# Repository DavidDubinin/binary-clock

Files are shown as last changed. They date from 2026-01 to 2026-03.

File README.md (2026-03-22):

# BINARY CLOCK SIGMA EDITION AVR CODE - ATMEGA48

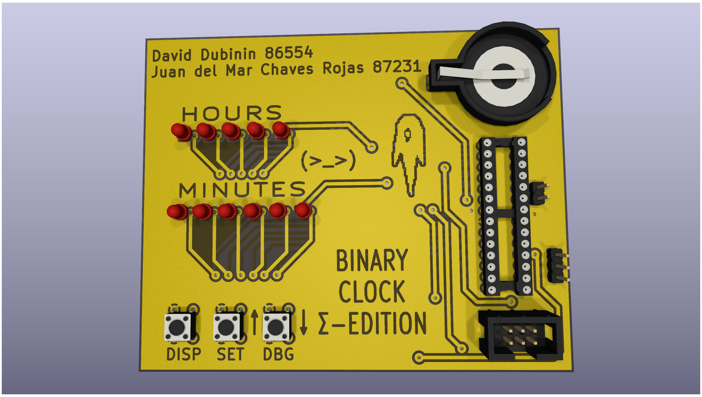
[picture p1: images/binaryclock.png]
pcb_render

schematic
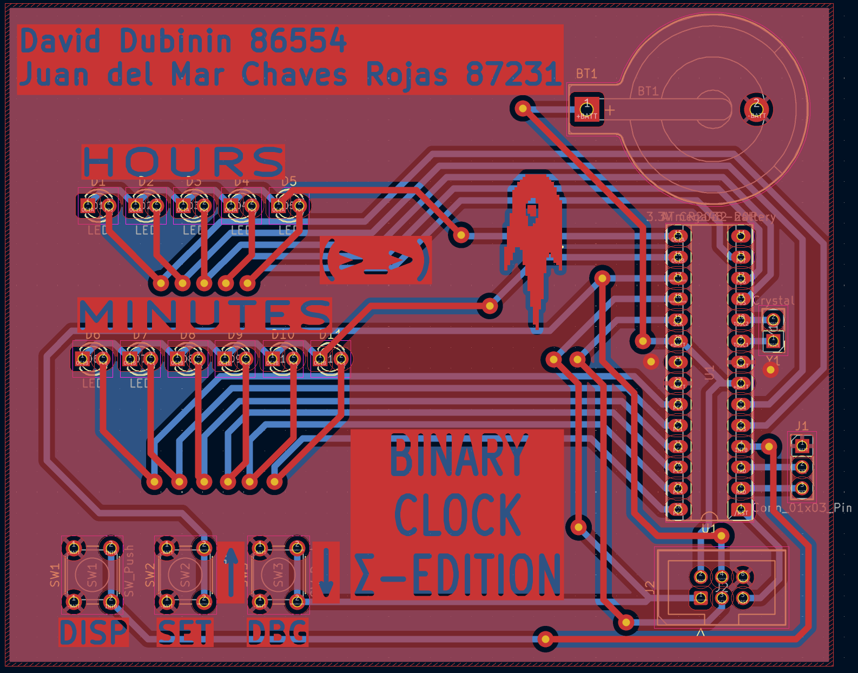
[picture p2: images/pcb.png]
pcb


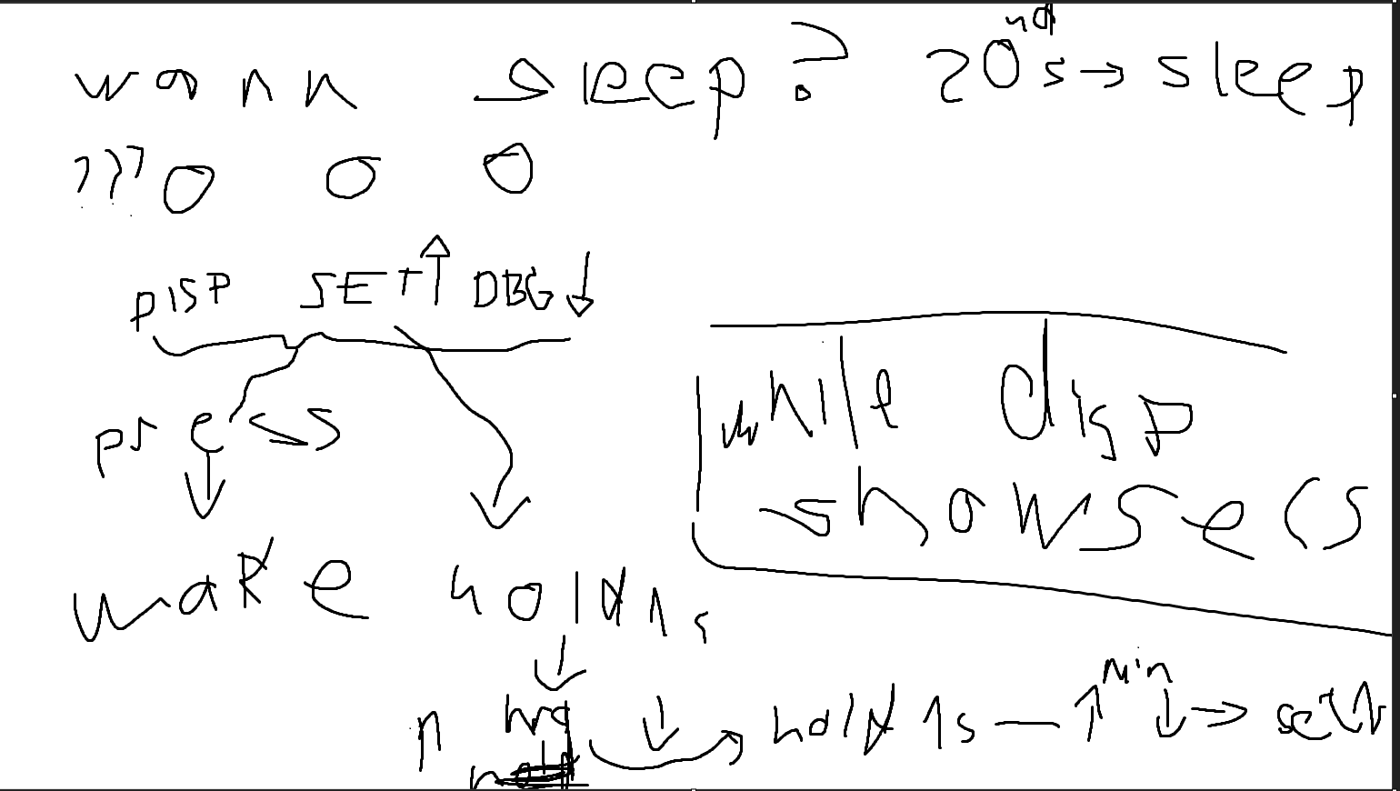
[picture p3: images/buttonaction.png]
buttonaction

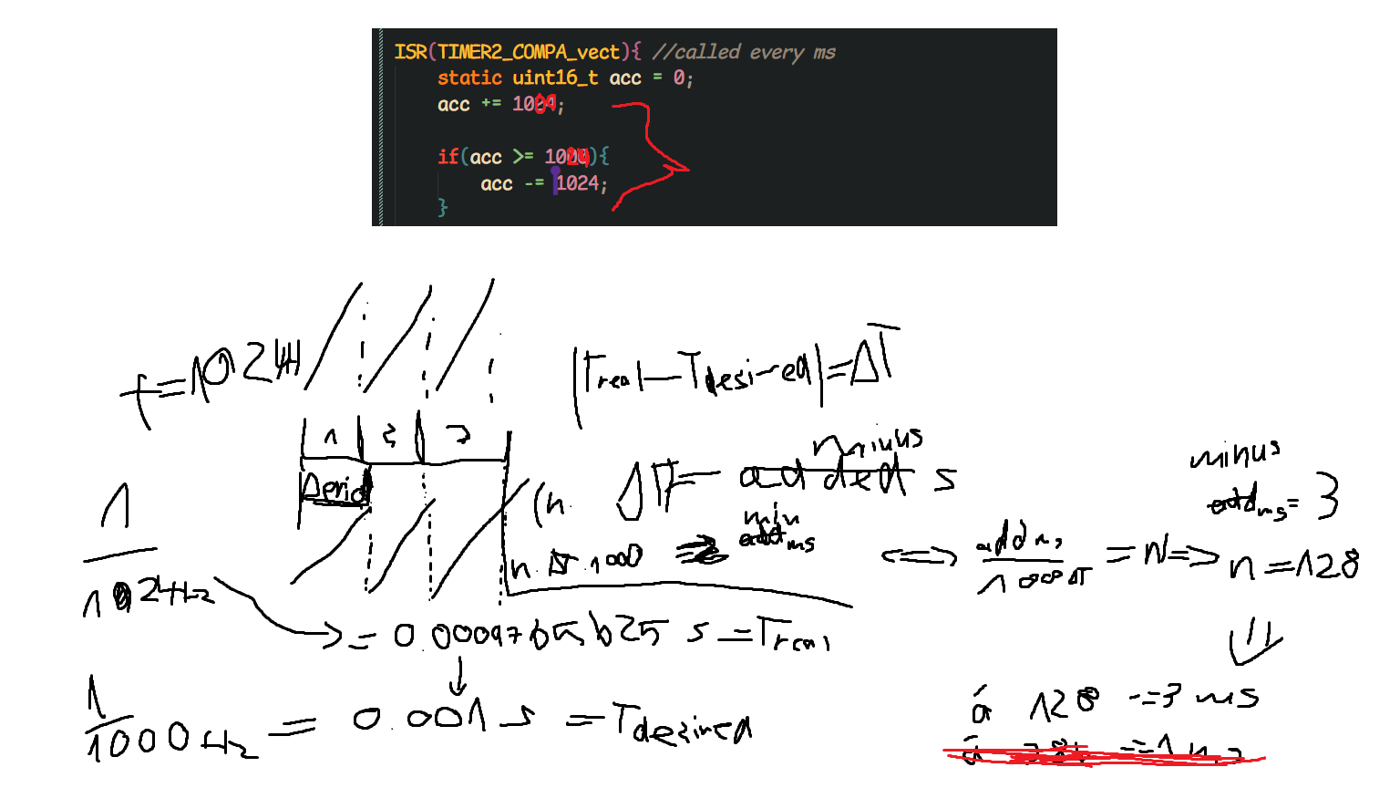
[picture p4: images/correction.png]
correction

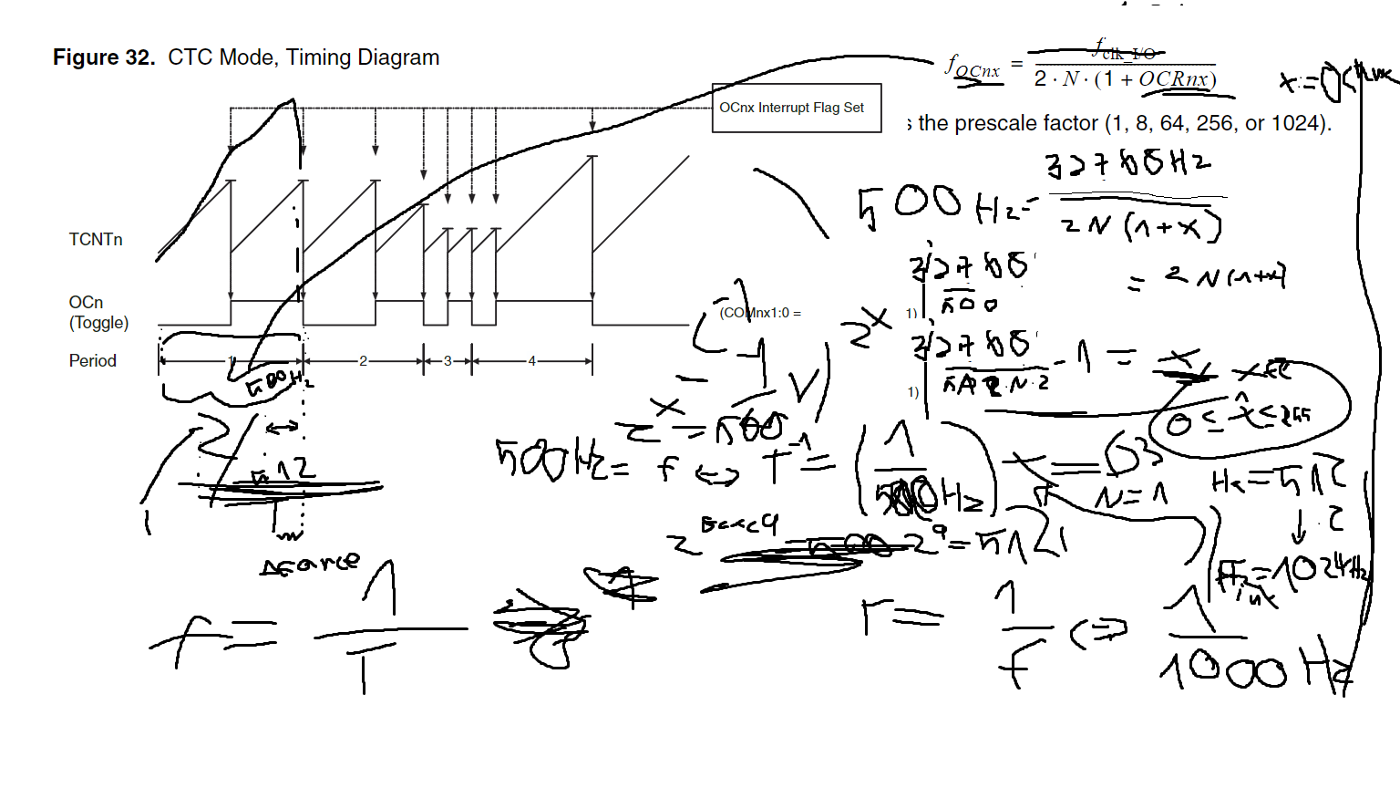
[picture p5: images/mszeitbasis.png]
mszeitbasis

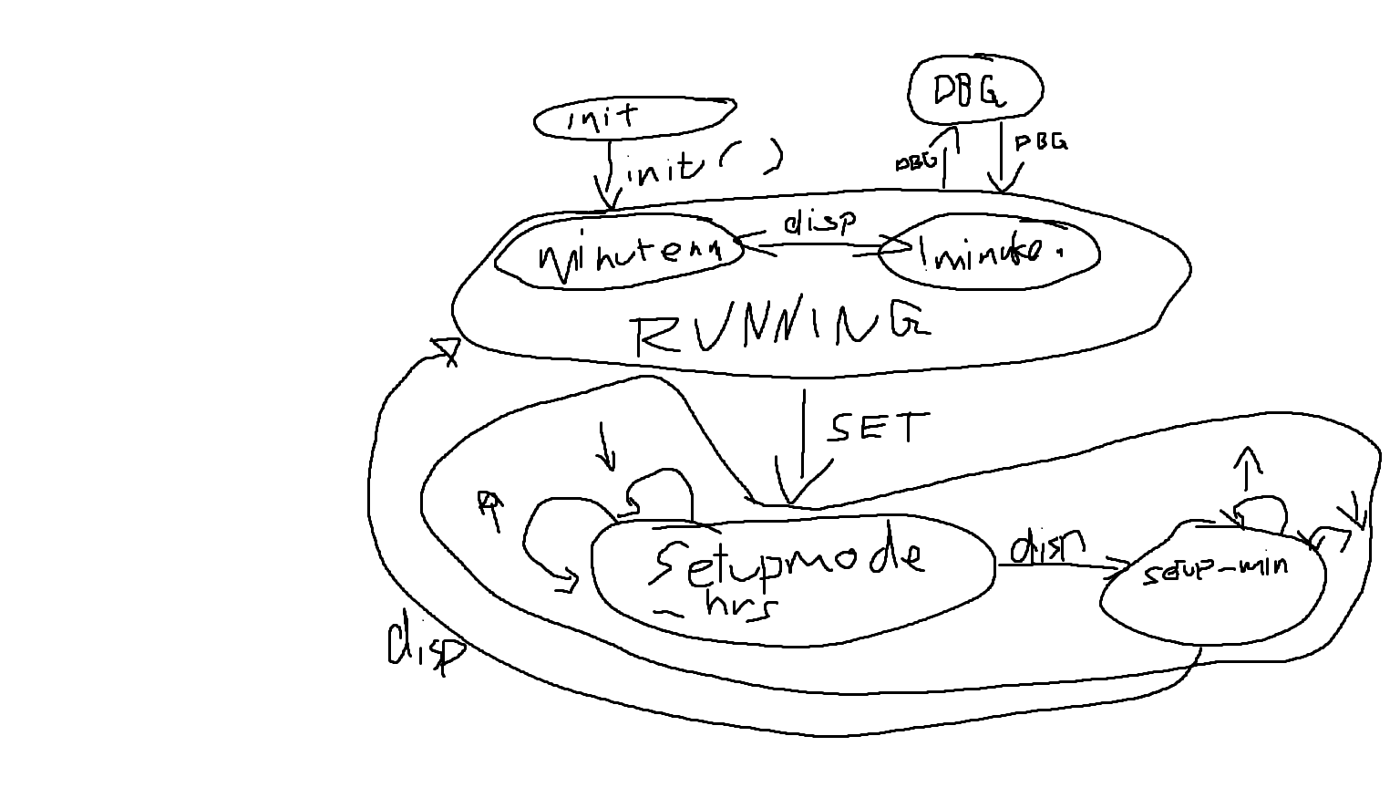
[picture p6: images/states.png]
states


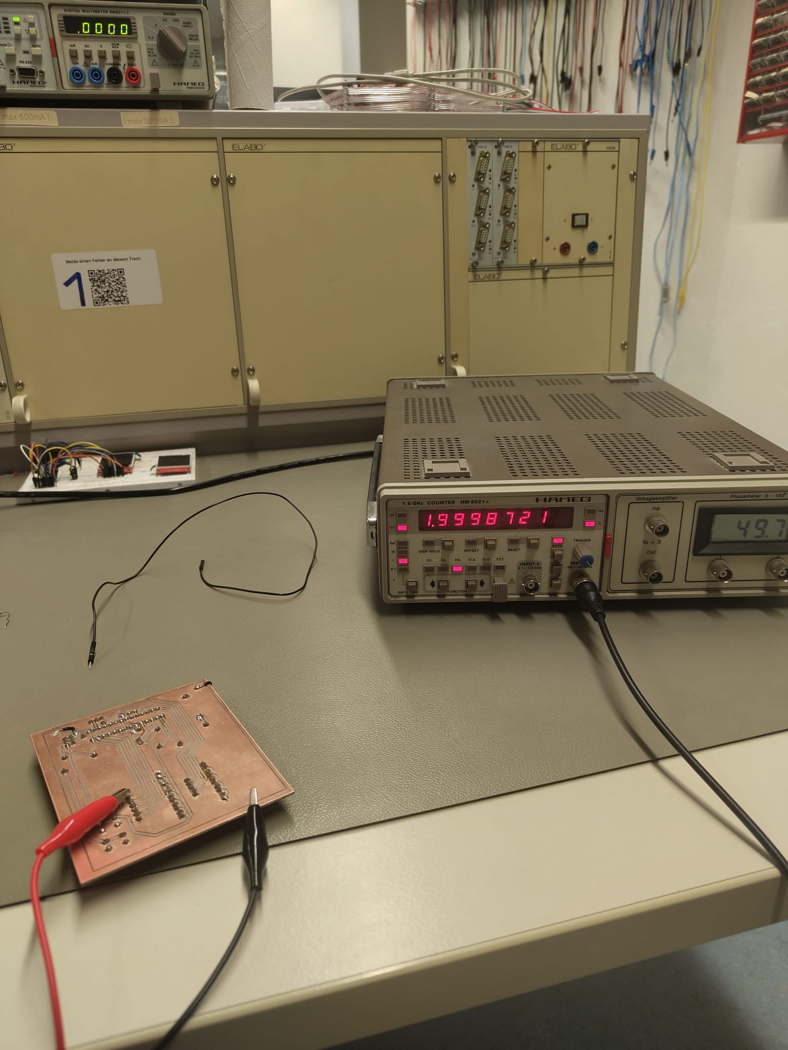
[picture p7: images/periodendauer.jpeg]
periodendauer

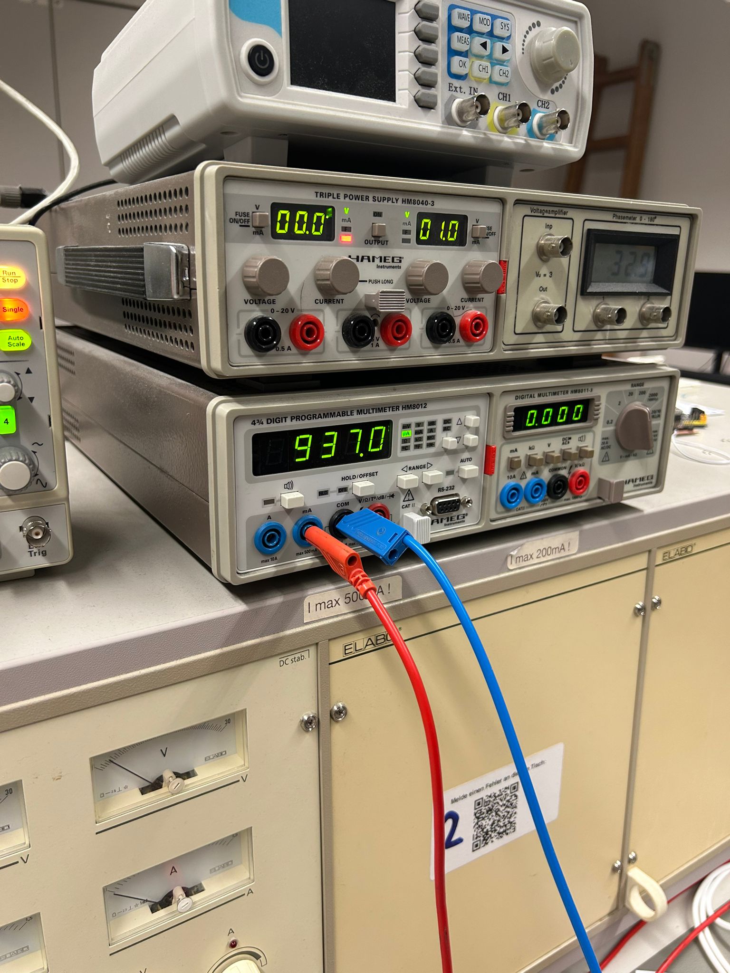
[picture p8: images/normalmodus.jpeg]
normalmodus

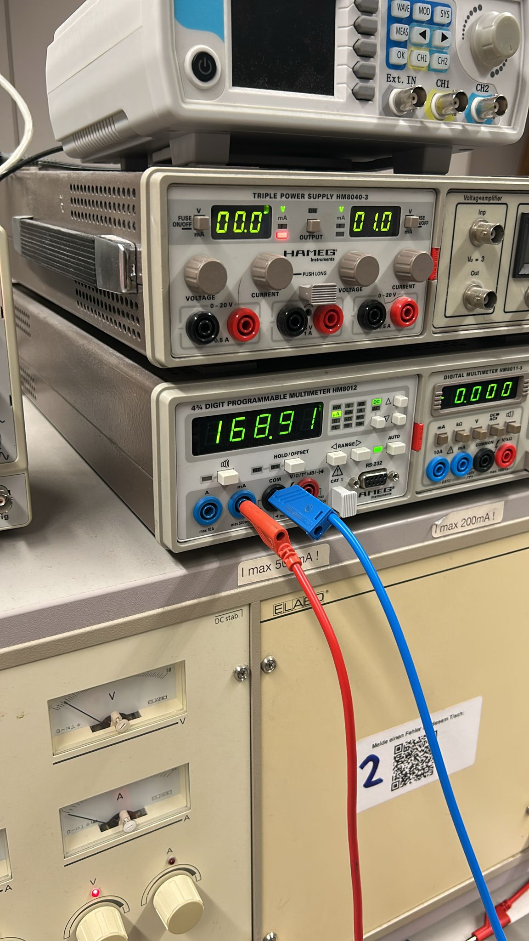
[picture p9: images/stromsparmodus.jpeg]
stromsparmodus

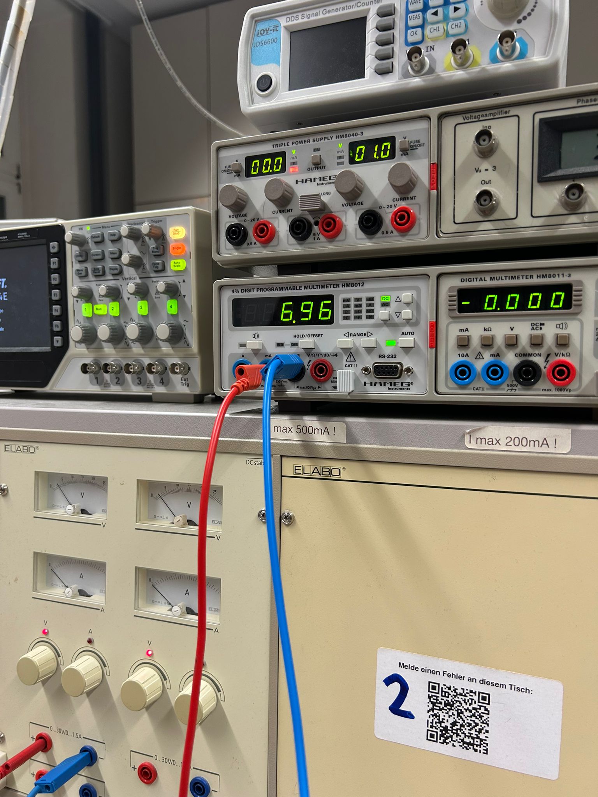
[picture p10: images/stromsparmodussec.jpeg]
stromsparmodussec

  
Prüufung (Folie 1/2)  
▶ Präsentation + Fachfragen (20min) Ihrer Lösung der Komplexaufgabe  
  
Komplexaufgabe  
▶ Binäre Ausgabe auf 11 LED’s mit hardware PWM Helligkeitssteuerung (OC1x-Pin)  
▶ Steuerung über Taster (INT0,x, y)  
▶ Sleepmode mit Beweis der reduzierten Leistungsaufnahme, Batterielaufzeit  
▶ Zeitbasis über Timer und Uhrenquarz, mit Genauigkeitsmessung  
▶ RS232 Debug-Interface (mindestens setzen und lesen der Zeit)  
  
Fachfragen  
▶ Im Rahmen der Prüfung werden wir Ihnen eine Schaltung (ähnlich der Ihrer Uhr)
vorgeben an der Sie live eine Aufgabe lösen werden.  
▶ Als Hilfsmittel haben Sie hierfür Ihren Sourcecode sowie das Datenblatt des
ATmega.  

---
  
//selbst gemessen  
I_active= 937.00 μA 
I_powersave= 168.91 μA  
I_powersavesec = 6.96 μA  
U=3.5V  
  
Leistungsaufnahme
P_active = 937.00 μA * 3.5V = 3.2795mW  
P_powersave = 168.91 μA * 3.5V = 591.185μW
P_powersavesec = 6.96 μA  * 3.5V = 24.36μW
  
Bei Varta CR2032 mit Kapazität von 230 mAh:  
Lebensdauer in Stunden = (Kapazität in Ah/Strom in A)  
Lebensdauer = (0,230Ah/0,000937A) = 245,46 Stunden  
Lebensdauer = (0,230Ah/0,00016891A) = 1.361,67 Stunden  
d.h. 10,23 Tage (Ohne Sleepmode) und 56,74 Tage (Mit Sleepmode)  
  
Und mit !!1s!!-Zeitbasis in Sleepmode:  
Lebensdauer = (0,230Ah/0,00000696A) = 38.045,98 Stunden = 1.585,25 Tage = 4,34 Jahre  

Das Delta zwischen den Leistungsaufnahmen im sleepmode mit ms oder sek Zeitbasis lässt sich dadurch erklären, dass bei der Millisekunden variante der Mikrocontroller wegen der hohen frequenz an Timer2 compare-match interrupts viel öfter aufwacht, um diese abzuarbeiten.
  
T=1.9998721s (an aus zyklus)  
T/2 = 0.99993605 
  
=> ((1s-0.99993605s)\*1000\*1000)/1s \≈ 64μs/1s = +64ppm  
Die Uhr geht also etwas zu schnell. Hochgerechnet führt das zu einem wöchentlichen Drift von 64μs/1000/1000*(60\*60\*24\*7)= +38.7072s
Das könnte man durch trial & error in der Software kompensieren, ähnlich wie bereits getan, um die Millisekunden-Zeitbasis zu implementieren.

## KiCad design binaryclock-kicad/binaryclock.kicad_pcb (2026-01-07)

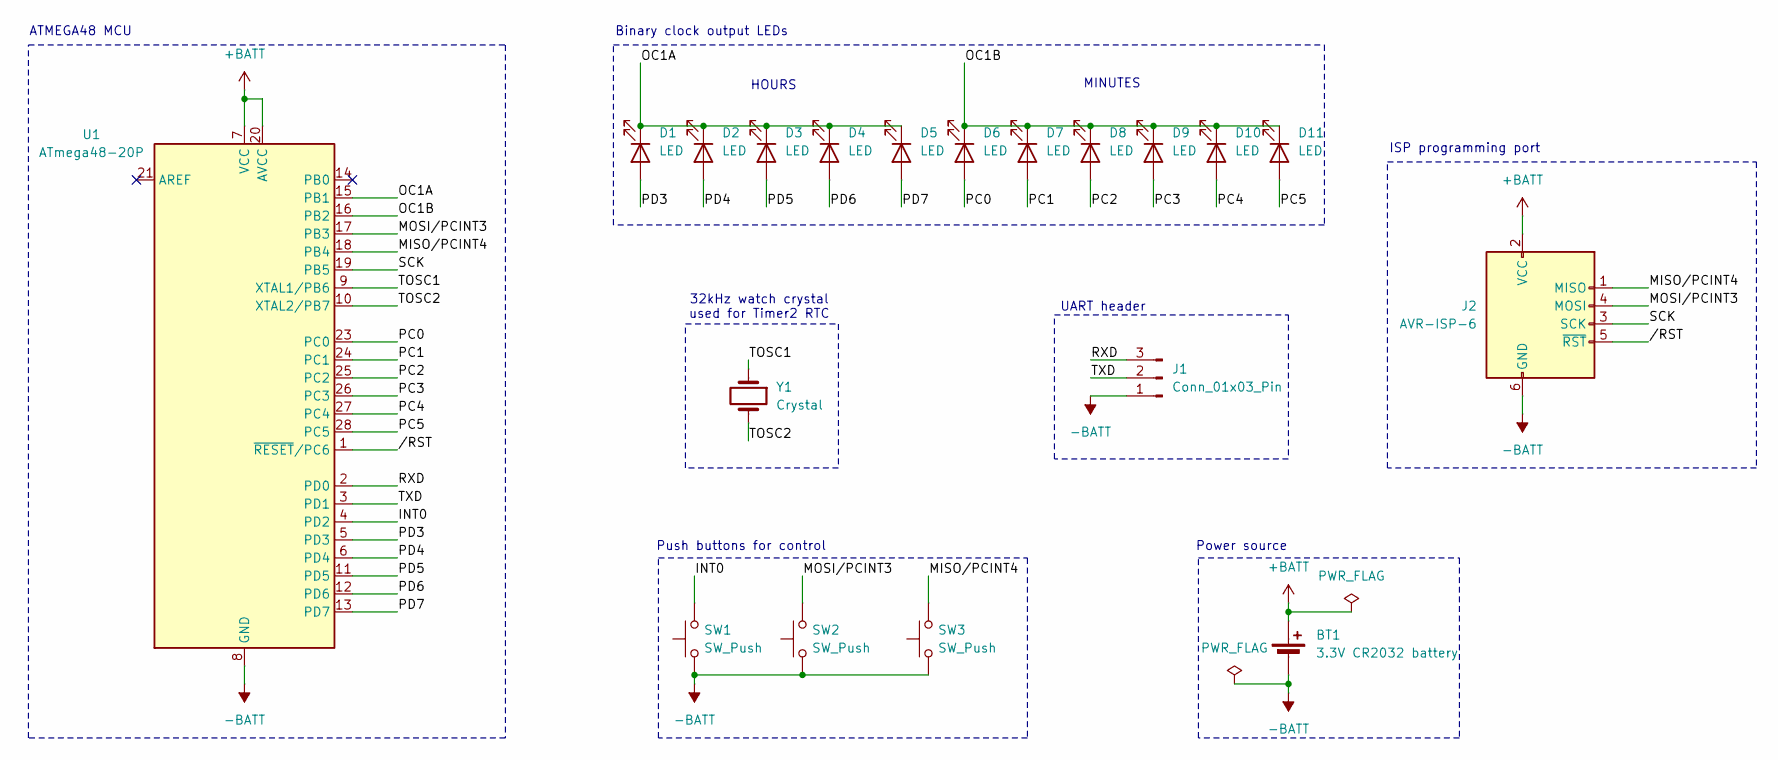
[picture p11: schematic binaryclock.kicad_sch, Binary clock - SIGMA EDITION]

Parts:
BT1: 3.3V CR2032 battery; BatteryHolder_Keystone_103_1x20mm
D1, D2, D3, D4, D5, D6, D7, D8, D9, D10, D11: LED; LED_D3.0mm
J1: Conn_01x03_Pin; PinHeader_1x03_P2.54mm_Vertical
J2: AVR-ISP-6; IDC-Header_2x03_P2.54mm_Vertical
SW1, SW2, SW3: SW_Push; SW_PUSH_6mm
U1: ATmega48-20P; DIP-28_W7.62mm_Socket_LongPads
Y1: Crystal; PinHeader_1x02_P2.54mm_Vertical

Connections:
+BATT: BT1.1 (+), J2.2 (VCC), U1.7 (VCC), U1.20 (AVCC)
-BATT: BT1.2 (-), J1.1, J2.6 (GND), SW1.1, SW2.1, SW3.1, U1.8 (GND), U1.22 (GND)
/INT0: SW1.2, U1.4 (PD2)
/MISO/PCINT4: J2.1 (MISO), SW3.2, U1.18 (PB4)
/MOSI/PCINT3: J2.4 (MOSI), SW2.2, U1.17 (PB3)
/OC1A: D1.1 (K), D2.1 (K), D3.1 (K), D4.1 (K), D5.1 (K), U1.15 (PB1)
/OC1B: D6.1 (K), D7.1 (K), D8.1 (K), D9.1 (K), D10.1 (K), D11.1 (K), U1.16 (PB2)
/PC0: D6.2 (A), U1.23 (PC0)
/PC1: D7.2 (A), U1.24 (PC1)
/PC2: D8.2 (A), U1.25 (PC2)
/PC3: D9.2 (A), U1.26 (PC3)
/PC4: D10.2 (A), U1.27 (PC4)
/PC5: D11.2 (A), U1.28 (PC5)
/PD3: D1.2 (A), U1.5 (PD3)
/PD4: D2.2 (A), U1.6 (PD4)
/PD5: D3.2 (A), U1.11 (PD5)
/PD6: D4.2 (A), U1.12 (PD6)
/PD7: D5.2 (A), U1.13 (PD7)
/RXD: J1.3, U1.2 (PD0)
/SCK: J2.3 (SCK), U1.19 (PB5)
/TOSC1: U1.9 (XTAL1/PB6), Y1.1
/TOSC2: U1.10 (XTAL2/PB7), Y1.2
/TXD: J1.2, U1.3 (PD1)
//RST: J2.5 (~RST), U1.1 (~RESET/PC6)

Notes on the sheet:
UART header
Push buttons for control
Power source
ISP programming port
32kHz watch crystal used for Timer2 RTC
HOURS
Binary clock output LEDs
MINUTES
ATMEGA48 MCU

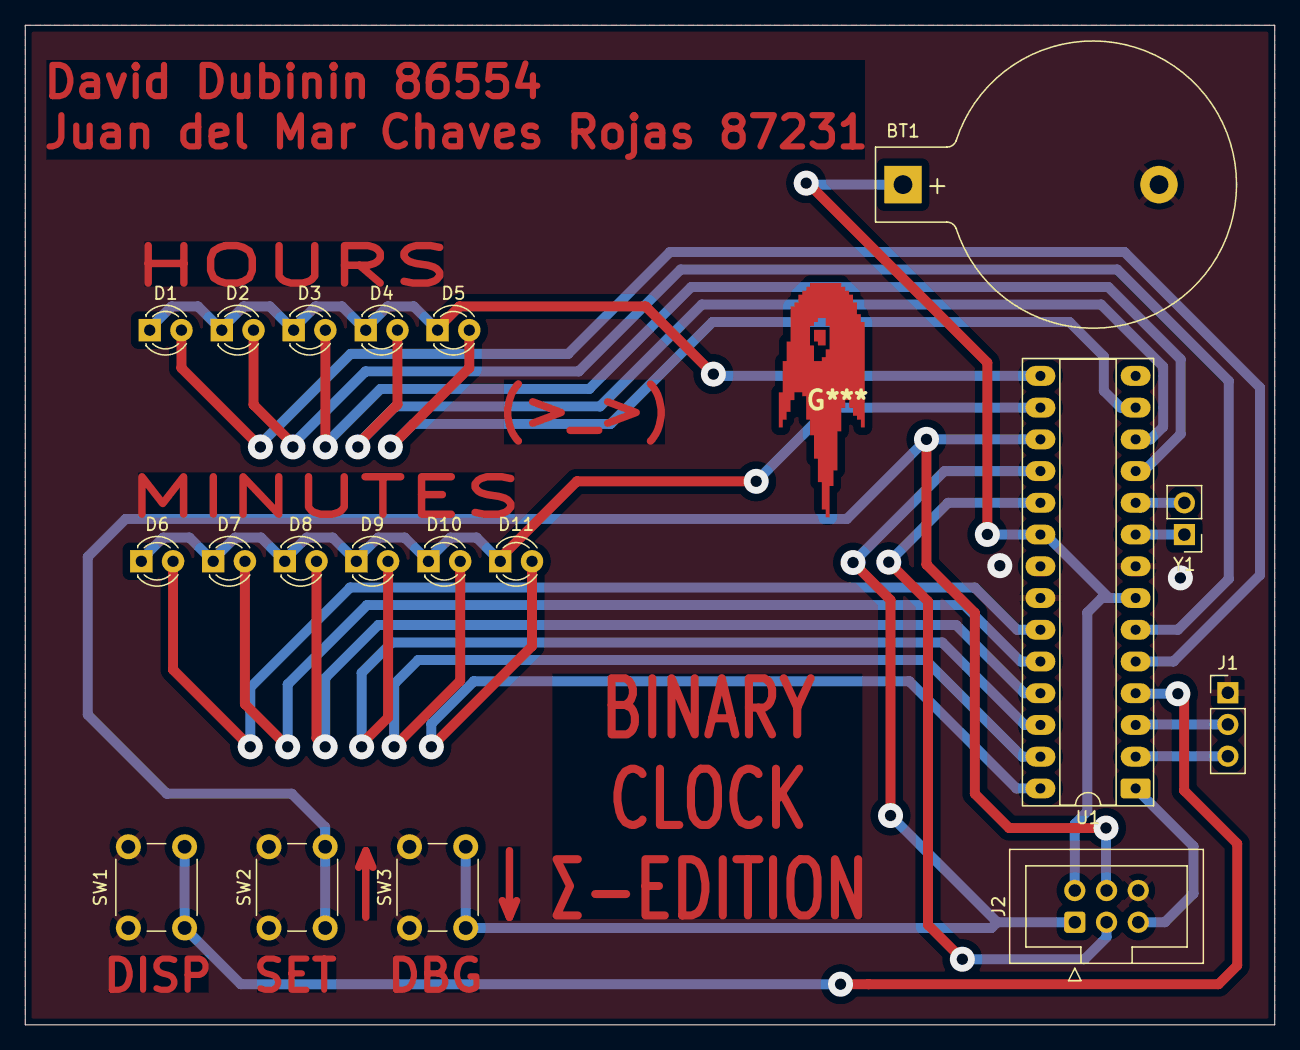
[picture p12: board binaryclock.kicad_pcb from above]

Board: 2 copper layers, 100.0 x 80.0 mm, 19 parts (0 on the bottom side), 24 nets.

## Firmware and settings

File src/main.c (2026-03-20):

#include "buttons.h"//button interrupts
#include "time.h"//1ms interrupt
#include "uart.h"
#include "state.h"

int main(void){
  while(1){
    switch (state) {
      case INIT:
        initState();
        break;
      
      case SHOW_MINUTES:
        showMinutesState();
        break;

      case SHOW_SECONDS:
        showSecondsState();
        break;

      case SETUP_HOURS:
        setupHoursState();
        break;

      case SETUP_MINUTES:
        setupMinutesState();
        break;
      
      case DBG:
        debugState();
        break;

      default:
        state = INIT;
        break;
    }
  }
}

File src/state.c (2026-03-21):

#include "state.h"

#include "driver.h"//alles
#include "buttons.h"//buttonFlags
#include "time.h"//Time types
#include "sleepTimer.h"//configMinimalPower()
#include "uart.h"

#include <avr/interrupt.h>
#include <util/atomic.h>

#define UP 0
#define DOWN 1

volatile State state = INIT;
Time newTime;

/*----------------
STATE CHANGE LOGIC
----------------*/

static void count_reversible(uint8_t up){
    newTime.seconds = 0;
    newTime.milliseconds = 0;
    TimeFlags newFlags = {0};

    if(state == SETUP_HOURS) {
        newFlags.hourPassed = 1;
    }
    else if(state == SETUP_MINUTES) {
        newFlags.minutePassed = 1; 
    }
    incrementTimeSetup_reversible(&newTime, &newFlags, up);   
    setLeds(newTime.hours, newTime.minutes);
}

static void count(void){
    uint8_t up = 0;
    uint8_t down = 0;

    ATOMIC_BLOCK(ATOMIC_RESTORESTATE){
    //countUp
        if(buttonFlags.setPressed){
            buttonFlags.setPressed = 0;
            up = 1;
        }

    //countDown
        if(buttonFlags.dbgPressed){
            buttonFlags.dbgPressed = 0;
            down = 1;
        }
    }
    
    if(up){
        count_reversible(UP);
    }
    
    else if(down){
        count_reversible(DOWN);
    }
}




/*------------
STATE LOGIC
------------*/

void initState(void) {
    cli();
    initLeds();
    initButtons();
    initPwm();
    initQuartz_ms();
    configMinimalPower();
    initUart();

    Time t = getTime();
    setLeds(t.hours, t.minutes);

    state = SHOW_MINUTES;
    sei();
}

void showMinutesState(void){
    trySleep();
    uint8_t dispPressed = 0;
    uint8_t setPressed = 0;
    uint8_t dbgPressed = 0;
    uint8_t minPassed = 0;

    ATOMIC_BLOCK(ATOMIC_RESTORESTATE) {
        //toggleMinutesMode
        if(buttonFlags.dispPressed){
            buttonFlags.dispPressed = 0;
            dispPressed = 1;
        }

        //enterSetup
        if(buttonFlags.setPressed) {
            buttonFlags.setPressed = 0;
            setPressed = 1;
        }
        
        //update Leds 
        if(timeFlags_external.minutePassed){
            timeFlags_external.minutePassed = 0;
            minPassed = 1;
        }

        //enterDbg
        if(buttonFlags.dbgPressed) {
            buttonFlags.dbgPressed = 0;
            dbgPressed = 1;
        }
    }

    if(setPressed){
        newTime = getTime();
        state = SETUP_HOURS;
        return;
    }
    

    else if(dispPressed) {
        Time t = getTime();
        setLeds(t.hours,t.seconds);
        state = SHOW_SECONDS;
        return;
    }

    else if(dbgPressed){
        state = DBG;
        return;
    };

    if(minPassed){
        Time t = getTime();
        setLeds(t.hours, t.minutes);
    }
}

void showSecondsState(void){
    trySleep();
    uint8_t dispPressed = 0;
    uint8_t setPressed = 0;
    uint8_t dbgPressed = 0;
    uint8_t secPassed = 0;

    ATOMIC_BLOCK(ATOMIC_RESTORESTATE) {
        //toggleMinutesMode
        if(buttonFlags.dispPressed){
            buttonFlags.dispPressed = 0;
            dispPressed = 1;
        }

        //enterSetup
        if(buttonFlags.setPressed) {
            buttonFlags.setPressed = 0;
            setPressed = 1;
        }
        
        //update Leds 
        if(timeFlags_external.secondPassed){
            timeFlags_external.secondPassed = 0;
            secPassed = 1;
        }

        //enterDbg
        if(buttonFlags.dbgPressed) {
            buttonFlags.dbgPressed = 0;
            dbgPressed = 1;
        }
    }

    if(setPressed){
        newTime = getTime();
        state = SETUP_HOURS;
        return;
    }
    

    else if(dispPressed) {
        Time t = getTime();
        setLeds(t.hours,t.minutes);
        state = SHOW_MINUTES;
        return;
    }

    else if(dbgPressed){
        state = DBG;
        return;
    }

    if(secPassed){
        Time t = getTime();
        setLeds(t.hours, t.seconds);
    }
}

void setupHoursState(void) {
    trySleep();
    //continueSetup
    ATOMIC_BLOCK(ATOMIC_RESTORESTATE) {
        if(buttonFlags.dispPressed){
            buttonFlags.dispPressed = 0;
            state = SETUP_MINUTES;
            return;
        }
    }

    count();
}

void setupMinutesState(void) {
    trySleep();
    uint8_t dispPressed = 0;
    //finishSetup
    ATOMIC_BLOCK(ATOMIC_RESTORESTATE) {
        if(buttonFlags.dispPressed){
            buttonFlags.dispPressed = 0;
            dispPressed = 1;
        }
    }
    
    if(dispPressed) {
        setTime(&newTime);
        state = SHOW_MINUTES;
        return;
    }
    
    count();
}

void debugState(void){
    processUart();
    uint8_t dbgPressed = 0;
    //toggleDbg
    ATOMIC_BLOCK(ATOMIC_RESTORESTATE) {
        if(buttonFlags.dbgPressed){
            buttonFlags.dbgPressed = 0;
            dbgPressed = 1;
        }
    }
    if(dbgPressed) {
        Time t = getTime();
        setLeds(t.hours, t.minutes);
        state = SHOW_MINUTES;
        return;
    }
}

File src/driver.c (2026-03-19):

#include "driver.h"
#include <avr/interrupt.h>

#include <util/atomic.h>

void initLeds(void) {
    DDRD |= (1 << PD3) | (1 << PD4) | (1 << PD5) | (1 << PD6) | (1 << PD7); // Stundenpins, 5 bit
    DDRC |= (1 << PC0) | (1 << PC1) | (1 << PC2) | (1 << PC3) | (1 << PC4) | (1 << PC5); // Minutenpins, 6 bit
}

void disableLeds(void){
    PORTD &= ~(1 << PD3) & ~(1 << PD4) & ~(1 << PD5) & ~(1 << PD6) & ~(1 << PD7); // Stundenpins, 5 bit
    PORTC &= ~(1 << PC0) & ~(1 << PC1) & ~(1 << PC2) & ~(1 << PC3) & ~(1 << PC4) & ~(1 << PC5); // Minutenpins, 6 bit
}

void initButtons(void) {
    //set Button pins as inputs
    DDRD &= ~(1 << PD2);
    DDRB &= ~(1 << PB3) & ~(1 << PB4);
    //enable internal pullups for Buttons
    PORTD |= (1 << PD2);
    PORTB |= (1 << PB3) | (1 << PB4);

    //set INT0 trigger to falling edge
    EICRA |= (1 << ISC01);
    EICRA &= ~(1 << ISC00);
    //Enable INT0
    EIMSK |= (1 << INT0);

    //Enable PCINT7..0 interrupt und Maske for PCINT3..4
    PCICR |= (1 << PCIE0);
    PCMSK0 |= (1 << PCINT3) | (1 << PCINT4);
}
 
void initPwm(void) {
    DDRB |= (1 << DDB1) | (1 << DDB2); // OC1A/PB1 bzw OC1B/PB2 auf Output für Stunden/Minuten

    TCCR1A |= (1 << WGM10) | (1 << WGM11) | (1 << COM1A1) 
            | (1 << COM1B1) | (1 << COM1A0) | (1 << COM1B0);
            
    TCCR1B |= (1 << WGM12) | (1 << CS10);
    TCCR1B &= ~(1 << WGM13) & ~(1 << CS11) & ~(1 << CS12);

    OCR1A = (1023 * DUTY_CYCLE) / 100;
    OCR1B = (1023 * DUTY_CYCLE) / 100;
}

//Watch Crystal 32 768 Hz, Prescaler 128, F_OCnx = 1/2 Hz (1 interrupt per sec) => OCRnx = 255  
//Toggle OC2A on Compare Match, CTC Mode, TOP=OCR2A
void initQuartz_seconds(void){
    //1. Disable the Timer/Counter2 interrupts by clearing OCIE2x and TOIE2
    TIMSK2 &= ~(1<<OCIE2A) & ~(1<<OCIE2B) & ~(1<<TOIE2);

    //2. Select clock source by setting AS2 as appropriate
    //Enable Asynchronous Timer/Counter2
    ASSR |= (1 << AS2);

    //3. Write new values to TCNT2, OCR2x, and TCCR2x.
    //Toggle OC2A on Compare Match

    TCNT2 = 0x00; //reset timer
    TCCR2A |= (1 << COM2A0);
    TCCR2A &= ~(1 << COM2A1);

    //CTC-Mode
    TCCR2A |= (1 << WGM21);
    TCCR2A &= ~(1 << WGM20);
    TCCR2B &= ~(1 << WGM22);

    //CS selection mit Prescaler = 128
    TCCR2B |= (1 << CS20) | (1 << CS22);
    TCCR2B &= ~(1 << CS21);

    //Compare Match bei Timer = 255 => OC2A Interrupt Flag Set
    OCR2A = 0xFF;

    //4. To switch to asynchronous operation: Wait for TCN2xUB, OCR2xUB, and TCR2xUB
    //ASSR = xxx1 1111 BAD
    //ASSR = xxx0 0000
    while(ASSR & ((1<<TCN2UB) | (1<<OCR2AUB) | (1<<OCR2BUB) | (1<<TCR2AUB) | (1<<TCR2BUB))){
    __builtin_avr_nop(); // sigma approved!!!
    }

    //5. Clear the Timer/Counter2 Interrupt Flags
    TIFR2 |= (1 << OCF2B) | (1 << OCF2A) | (1 << TOV2);

    //6. Enable interrupts, if needed
    //Enable Output Compare Match Interrupt A
    TIMSK2 |= (1 << OCIE2A);
}



//Watch Crystal 32 768 Hz, Prescaler 1, F_OCnx = 512Hz (1 interrupt per ms) => OCRnx = 31  
//Toggle OC2A on Compare Match, CTC Mode, TOP=OCR2A

// F_OCnx = F_clkIO / (2 * N * (1 + OCRnx))
// F_Interrupt = 2 * F_OCnx (2x Interrupts in einer Periode CTC)
// F_interrupt = 2 * ( F_clkIO / (2 * N * (1 + OCRnx)) )
// F_interrupt = 2 * ( 32 768Hz / (2 * 1 * (1 + OCRnx)) )
// F_interrupt = 2 * ( 32 768Hz / (2 * 1 * (1 + 63)) ) = 512Hz F_Interrupts ↯ wollen aber 1024Hz 


// Gleichung
// 1024 Hz = 32 768Hz / (1*(1 + OCRnx))          | * 1*(1+OCRnx)
// 1024 Hz * (1 + OCRnx) = 32 768 Hz             | / 1024
// 1 + OCRnx = 32 768 Hz / 1024 Hz
// 1 + OCRnx = 32                                | - 1
// OCRnx = 31 bei 1024 Iterrupts/s

void initQuartz_ms(void){
    //1. Disable the Timer/Counter2 interrupts by clearing OCIE2x and TOIE2
    TIMSK2 &= ~(1<<OCIE2A) & ~(1<<OCIE2B) & ~(1<<TOIE2);

    //2. Select clock source by setting AS2 as appropriate
    //Enable Asynchronous Timer/Counter2
    ASSR |= (1 << AS2);

    //3. Write new values to TCNT2, OCR2x, and TCCR2x.
    //Toggle OC2A on Compare Match

    TCNT2 = 0x00; //reset timer
    TCCR2A |= (1 << COM2A0);
    TCCR2A &= ~(1 << COM2A1);

    //CTC-Mode
    TCCR2A |= (1 << WGM21);
    TCCR2A &= ~(1 << WGM20);
    TCCR2B &= ~(1 << WGM22);

    //CS selection mit Prescaler = 1 (= No prescaler)
    TCCR2B |= (1 << CS20);
    TCCR2B &= ~(1 << CS22) & ~(1 << CS21);

    //Compare Match bei Timer = 31 => OC2A Interrupt Flag Set | siehe Rechnung oben
    OCR2A = 31;

    //4. To switch to asynchronous operation: Wait for TCN2xUB, OCR2xUB, and TCR2xUB
    //ASSR = xxx1 1111 BAD
    //ASSR = xxx0 0000
    while(ASSR & ((1<<TCN2UB) | (1<<OCR2AUB) | (1<<OCR2BUB) | (1<<TCR2AUB) | (1<<TCR2BUB))){
    __builtin_avr_nop(); // sigma approved!!!
    }

    //5. Clear the Timer/Counter2 Interrupt Flags
    TIFR2 |= (1 << OCF2B) | (1 << OCF2A) | (1 << TOV2);

    //6. Enable interrupts, if needed
    //Enable Output Compare Match Interrupt A
    TIMSK2 |= (1 << OCIE2A);
}


void setLeds(uint8_t hourLedsVal, uint8_t minuteLedsVal) {
    ATOMIC_BLOCK(ATOMIC_RESTORESTATE){
        PORTD = __builtin_avr_insert_bits(0x01234FFF, hourLedsVal, PORTD); // portd 7 bis 3  stunden
        PORTC = __builtin_avr_insert_bits(0xFF012345, minuteLedsVal, PORTC); //portc 5 bis 0 Sekunden
    }
}

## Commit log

2025-12-17 added kicad stuff
    [binaryclock.kicad_pcb, binaryclock.kicad_sch]
2025-12-18 assigned footprints to components
    [binaryclock.kicad_sch]
2025-12-18 updated schematic svg
2025-12-26 initial pcb draft
    [binaryclock.kicad_pcb]
2025-12-26 passed drc
    [binaryclock.kicad_pcb, binaryclock.kicad_sch]
2025-12-26 idk what i did
    [binaryclock.kicad_pcb]
2025-12-28 prettified pcb
    [binaryclock.kicad_pcb]
2025-12-29 did some adjustments
    [binaryclock.kicad_pcb]
2025-12-31 created fabrication files
    [binaryclock-B_Cu.gbr, binaryclock-F_Cu.gbr, binaryclock-NPTH.drl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]
2025-12-31 wip pcb test
2026-01-06 pcb finalized
    [binaryclock.kicad_pcb]
2026-01-07 finished pcb
    [binaryclock.kicad_pcb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]
2026-01-07 TRUE FINAL PCB VERSION
    [binaryclock.kicad_pcb, binaryclock.kicad_sch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]
2026-03-03 pwm implemented, wip led setup
2026-03-04 fixed kicad project file
2026-03-06 wip buttons
2026-03-14 wip buttonshit?! lampenzeug
2026-03-17 tried to implement millis
2026-03-18 finished millisecond-based timebase, reworked rebounce, moved state logic out of time.c
    [driver.c, main.c, state.c]
2026-03-20 uart doesnt work!! :D
2026-03-20 UART DOESNT WORK
2026-03-21 finished uart
